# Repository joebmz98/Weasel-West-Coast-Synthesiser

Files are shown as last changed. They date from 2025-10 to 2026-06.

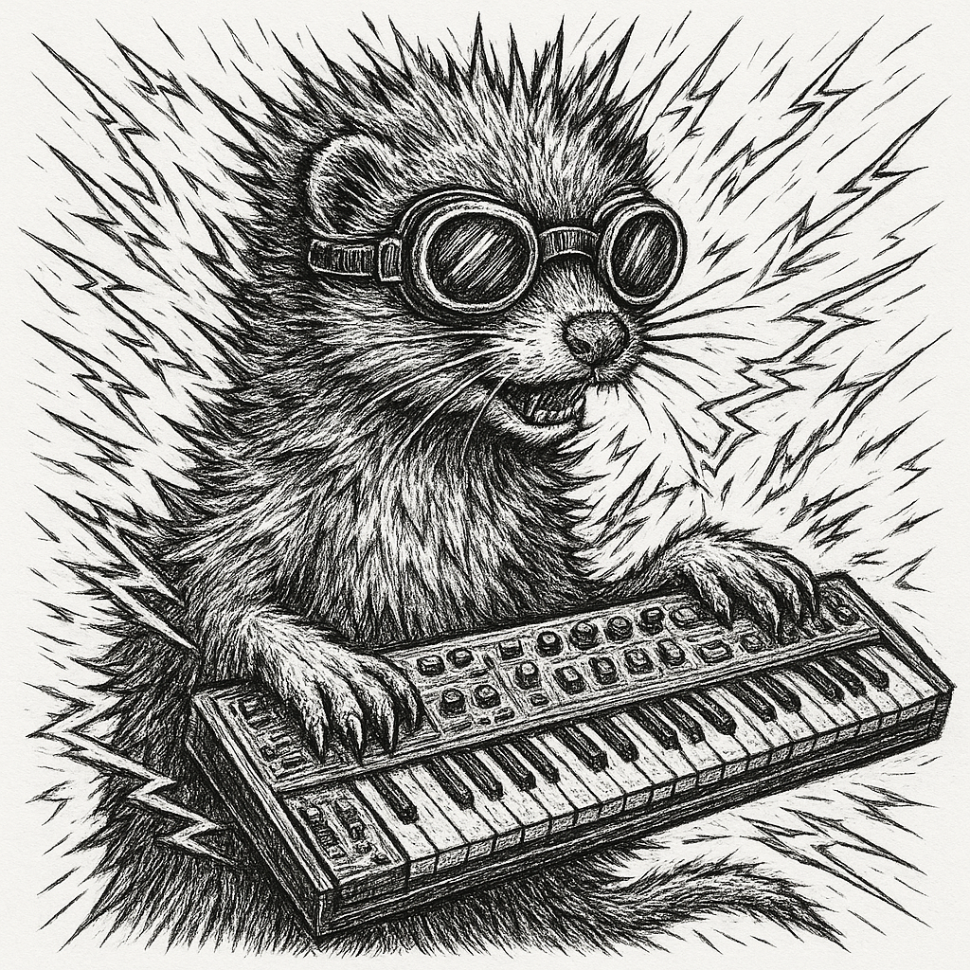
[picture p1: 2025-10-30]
docs/images/weaselDrawing_ai.png

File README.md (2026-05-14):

# WEASEL
### Buchla Music Easel Inspired Digital Synthesizer

**firmware version 0.1** | **hardware version 1.0**

---

Designed by **[.axs instruments](https://github.com/axsinstruments)**

---

## Overview

WEASEL is a digital synthesizer inspired by the iconic Buchla Music Easel, built around the Daisy Seed platform. It features a virtual patch bay that simulates a modular experience, allowing you to route modulation sources to destinations through an intuitive button matrix interface.

---

## Features

- **Complex Oscillator** with sine wave and morphable waveform (saw/triangle/square)
- **Modulation Oscillator** with sine, triangle, saw, and square waveforms
- **FM/AM Modulation** between oscillators
- **Wavefolder** for complex timbre shaping
- **Dual-channel Low Pass Gate (LPG)** with VCA/LP/COMBI modes
- **Buchla-style ASR Envelope Generator**
- **Pulsar Generator** (decaying envelope for rhythmic triggering)
- **Sample & Hold / Random Voltage Generator**
- **5-Step Sequencer** with per-step enable toggles
- **Virtual Patch Bay** (4x7 button matrix) for routing:
  - Sequencer CV → 7 destinations
  - Envelope → 7 destinations
  - Pulsar → 7 destinations
  - Random Voltage → 7 destinations
- **Internal Reverb**
- **MIDI Input** for note control and triggering

---

## Hardware Requirements

| Component | Details |
|---|---|
| **Microcontroller** | Daisy Seed |
| **ADC Resolution** | 16-bit |
| **Potentiometers** | 32 total (via 2x 16-channel multiplexers) |
| **Button Matrix 1** | 4x7 (virtual patch bay) |
| **Button Matrix 2** | 4x5 (mode selection & controls) |
| **Audio Output** | Stereo line out |
| **MIDI Input** | 3.5mm TRS (pin D14 / USART1 Rx) |

### Pin Mapping

**MUX1 (Pots 0-15)** – A0

| MUX Pin | Function |
|---|---|
| S0 | D0 |
| S1 | D1 |
| S2 | D2 |
| S3 | D3 |

**MUX2 (Pots 16-31)** – A1

| MUX Pin | Function |
|---|---|
| S0 | D4 |
| S1 | D5 |
| S2 | D6 |
| S3 | D7 |

---

## Potentiometer Functions

### MUX1 (Channels 0-15)

| CH | Function |
|----|---|
| 0 | Sequencer Step 1 CV |
| 1 | Sequencer Step 2 CV |
| 2 | Sequencer Step 3 CV |
| 3 | Sequencer Step 4 CV |
| 4 | Sequencer Step 5 CV |
| 5 | Attack Time |
| 6 | Sustain Duration |
| 7 | Decay/Release Time |
| 8 | Pulsar Period Modulation Control |
| 9 | Pulsar Period |
| 10 | Modulation Osc Freq Modulation Amount |
| 11 | Modulation Osc Frequency |
| 12 | Modulation Osc Fine Tune (±3 cents) |
| 13 | Modulation Osc Modulation Amount Depth |
| 14 | Modulation Osc Modulation Amount |
| 15 | Complex Osc Frequency Modulation Amount |

### MUX2 (Channels 16-31)

| CH | Function |
|----|---|
| 16 | Complex Osc Frequency |
| 17 | Complex Osc Fine Tune (±3 cents) |
| 18 | Complex Osc Wavefolder Modulation Amount |
| 19 | Complex Osc Wavefolder |
| 20 | Complex Osc Timbre (morph) |
| 21 | LPG1 Modulation Amount |
| 22 | LPG1 Level |
| 23 | LPG2 Modulation Amount |
| 24 | LPG2 Level |
| 25 | Clock Speed |
| 26 | Reverb Mix |
| 27-31 | Not Connected |

---

## Button Matrix Functions

### Matrix 1 (4x7) – Virtual Patch Bay

**Sources (Columns):**
- Col 0: Sequencer CV
- Col 1: Envelope
- Col 2: Pulsar
- Col 3: Random Voltage

**Destinations (Rows):**
- Row 0: Pulsar Period
- Row 1: Modulation Osc Frequency
- Row 2: Modulation Osc Modulation Amount
- Row 3: Complex Osc Pitch
- Row 4: Complex Osc Wavefolder Amount
- Row 5: LPG Channel 1 Level
- Row 6: LPG Channel 2 Level

### Matrix 2 (4x5) – Mode Controls

| Position | Function |
|---|---|
| X0+Y0 | Sequencer Length Cycle (3/4/5 steps) |
| X0+Y1 | Pulsar Mode Toggle (SEQ/MIDI/OSC) |
| X0+Y2 | Complex Osc Polarity Invert |
| X0+Y3 | Mod Osc LPG Mode Toggle (VCA/LP/COMBI) |
| X0+Y4 | Sequencer Step 2 Toggle |
| X1+Y0 | Sequencer Trigger Mode (CLOCK/PULSAR/MIDI) |
| X1+Y1 | Pulsar Clock Mode |
| X1+Y2 | MIDI Toggle (Complex + Mod Osc) |
| X1+Y3 | Random Trigger Mode (SEQ/PULSAR/MIDI) |
| X1+Y4 | Sequencer Step 3 Toggle |
| X2+Y1 | Mod Waveform Cycle |
| X2+Y2 | Complex Waveform Cycle |
| X2+Y4 | Sequencer Step 4 Toggle |
| X3+Y1 | FM/AM Toggle |
| X3+Y2 | LPG Mode Toggle (VCA/LP/COMBI) |
| X3+Y3 | Sequencer Step 1 Toggle |
| X3+Y4 | Sequencer Step 5 Toggle |

---

## Installation & Setup

### 1. Prerequisites

- [Arduino IDE](https://www.arduino.cc/en/software)
- [DaisyDuino](https://github.com/electro-smith/DaisyDuino) – Daisy platform for Arduino
- [MIDI Library](https://github.com/FortySevenEffects/arduino_midi_library)

### 2. Flashing the Firmware

1. Install DaisyDuino following the [official guide](https://github.com/electro-smith/DaisyDuino#installation)
2. Clone this repository
3. Open `weasel.ino` in Arduino IDE
4. Select **Daisy Seed** as the board
5. Upload the firmware

### 3. First Boot

- Connect audio output to the Daisy Seed's audio jack
- Connect a MIDI source to the TRS input (optional)
- Power via USB or external 5V
- The synthesizer will start with default settings

---

## Usage

### Basic Signal Flow

[Complex Osc] → [Wavefolder] → [LPG Ch1] → [Mixer] → [Output Filter] → [Reverb]
[Mod Osc] ──────────────────→ [LPG Ch2] ↗
     ↓
  (FM/AM to Complex Osc)

### Sequencer Operation

- The 5-step sequencer advances based on the selected trigger mode (Clock/Pulsar/MIDI)
- Each step's CV is set by its corresponding potentiometer
- Per-step toggles allow disabling individual steps
- Sequence length can be set to 3, 4, or 5 steps

### Envelope (Buchla ASR Style)

- **Attack**: Sets rise time
- **Sustain**: Sets gate duration
- **Release**: Sets fall time after gate ends

### Pulsar Generator

- Creates decaying envelopes for rhythmic triggering
- Can be synced to sequencer, MIDI note-on, or run freely as an LFO

### Low Pass Gate Modes

- **VCA**: Amplitude only (no filtering)
- **LP**: Low-pass filtering only
- **COMBI**: Both VCA and filtering (classic Buchla LPG behavior)

---

## MIDI Implementation

| Function | Details |
|---|---|
| **Input** | 3.5mm TRS (Type A) |
| **Baud Rate** | 31250 |
| **Note On** | Triggers sequencer, pulsar, and random (depending on mode) |
| **Note Pitch** | Controls Complex and/or Mod Osc frequencies when MIDI mode is enabled |

**MIDI Pin:** Digital pin 30 (D14 / USART1 Rx)

---

## Building from Source

### Dependencies

- `DaisyDuino` – Daisy hardware abstraction
- `MIDI` – MIDI input handling

### Compilation

The firmware is compatible with Arduino IDE. Select **Daisy Seed** from the boards menu and upload.

---

## License

**MIT License** – Copyright (c) 2024 .axs instruments

Permission is hereby granted, free of charge, to any person obtaining a copy of this software and associated documentation files, to deal in the Software without restriction, including without limitation the rights to use, copy, modify, merge, publish, distribute, sublicense, and/or sell copies of the Software.

THE SOFTWARE IS PROVIDED "AS IS", WITHOUT WARRANTY OF ANY KIND, EXPRESS OR IMPLIED.

---

## Support & Contributions

- **Issues:** Open a GitHub ticket
- **Custom Requests:** [axs.instruments@gmail.com](mailto:axs.instruments@gmail.com)
- **Contributions:** PRs welcome!

---

## Acknowledgments

Built with the [Daisy Platform](https://www.electro-smith.com/daisy) by Electro-Smith.

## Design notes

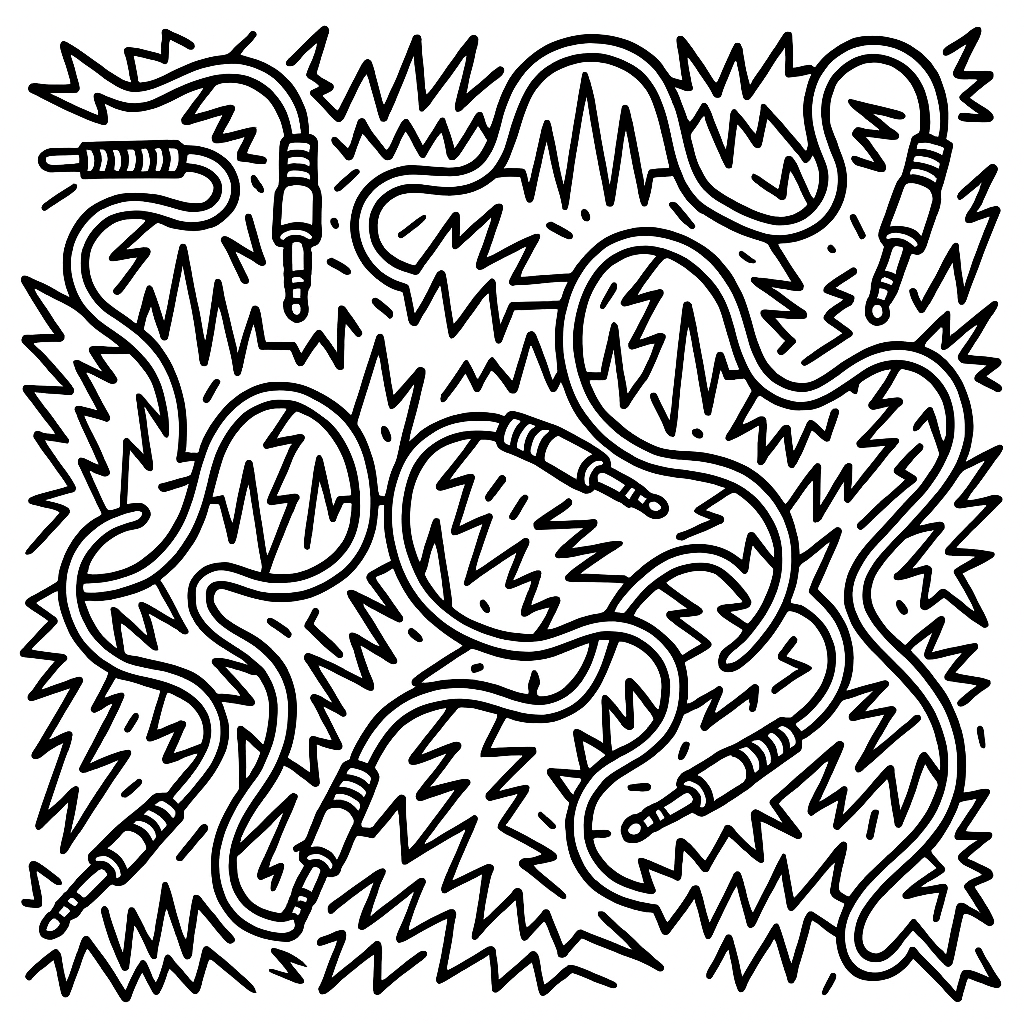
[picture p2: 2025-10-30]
docs/images/modularCables2_ai.png

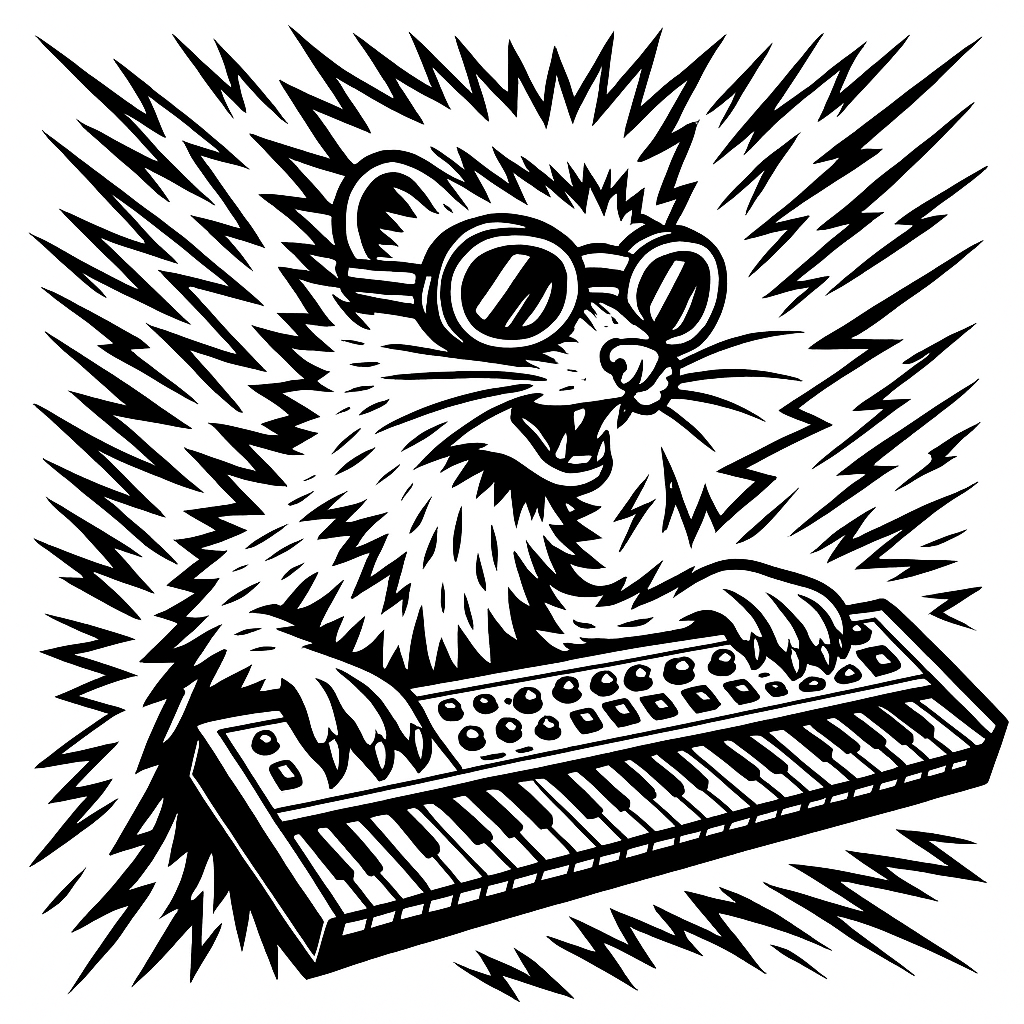
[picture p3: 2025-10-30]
docs/images/weaselDrawing2_ai.png

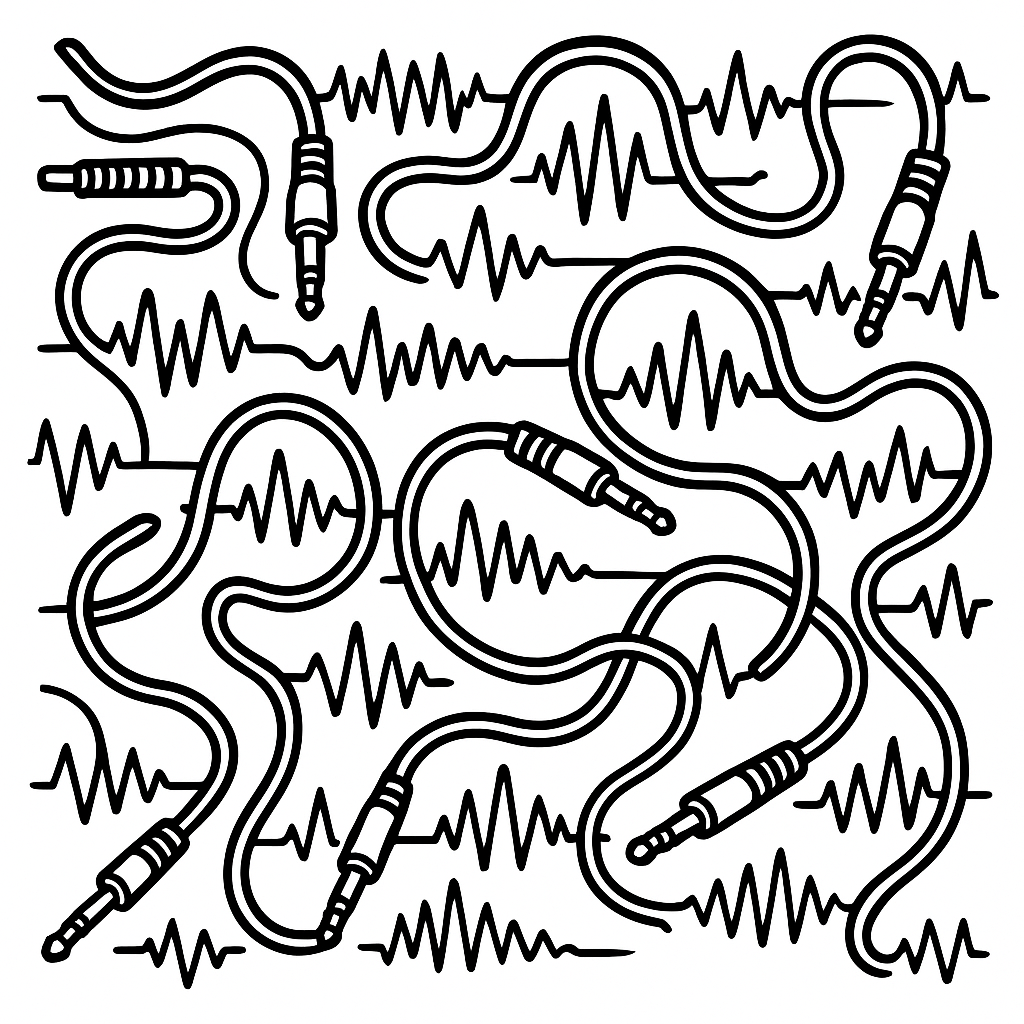
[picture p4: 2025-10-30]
docs/images/modularCables_ai.png

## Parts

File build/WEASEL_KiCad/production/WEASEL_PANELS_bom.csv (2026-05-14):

Designator | Footprint | Quantity | Value | LCSC Part #
_2, |  | 2

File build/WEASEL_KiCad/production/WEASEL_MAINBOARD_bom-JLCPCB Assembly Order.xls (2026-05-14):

JLCPCB BOM Tool - BOM Matching
BOM name：WEASEL_MAINBOARD_bom-JLCPCB Assembly Order.xlsx |  |  | Download Time：2026-05-14 16:15:40 |  |  |  | * Our matching results are updated in real-time, but stock and prices may change. If it's been over 24 hours, please re-match before placing your order.
PCB Assembled Qty：5 |  |  | Est. Total Price：88.7256
Your BOM |  |  |  |  | Matched Parts |  |  |  |  |  |  | Order Information
Top Designator | Bottom Designator | Comment | Footprint | JLCPCB Part # | Matches | Part # | Manufacturer | Footprint | Description | Category | Warning | JLCPCB Part # | Product link | Lib Type | Qty | Source | Total Price ($)
C1,C2,C31,C34,C35,C36,C37,C38,C39,C40,C41 |  | 100nF_0603_16V | 1206 |  | Select by Customer | CL31B104KCFNNNE | Samsung Electro-Mechanics | 1206 | 100V 100nF X7R ±10% 1206 Multilayer Ceramic Capacitors MLCC - SMD/SMT ROHS | Multilayer Ceramic Capacitors MLCC - SMD/SMT |  | C1945 | https://jlcpcb.com/partdetail/2297-CL31B104KCFNNNE/C1945 | Extended | 63 | 63 JLCPCB | 1.1466
C10,C11,C12,C13,C14,C15,C16,C17,C18,C19,C20,C21,C22,C23,C24,C25,C26,C27,C28,C29,C3,C30,C4,C5,C6,C7,C8,C9 |  | C_Generic | 1206 |  | Select by Customer | 1206B103K102NT | FH (Guangdong Fenghua Advanced Tech) | 1206 | 10nF 1kV X7R ±10% 1206 Multilayer Ceramic Capacitors MLCC - SMD/SMT ROHS | Multilayer Ceramic Capacitors MLCC - SMD/SMT |  | C9194 | https://jlcpcb.com/partdetail/9719-1206B103K102NT/C9194 | Extended | 150 | 150 JLCPCB | 1.8
C32 |  | 10uF | 1206 |  | Select by Customer | CL31A106KOHNNNE | Samsung Electro-Mechanics | 1206 | 10uF 16V X5R ±10% 1206 Multilayer Ceramic Capacitors MLCC - SMD/SMT ROHS | Multilayer Ceramic Capacitors MLCC - SMD/SMT |  | C1849 | https://jlcpcb.com/partdetail/2201-CL31A106KOHNNNE/C1849 | Extended | 15 | 15 JLCPCB | 0.5985
D1,D10,D11,D12,D13,D23,D24,D25,D26,D27,D28,D29 |  | 1N4148 | D_SOD-123 |  | Select by Customer | 1N4148W | Jiangsu Changjing Electronics Technology Co., Ltd. | SOD-123 | 1.25V@150mA 100V 150mA 1uA@75V 2A 4ns 500mW Independent SOD-123 Switching Diodes ROHS | Switching Diodes | 1.The comment (1N4148W) of this part does not match the one (1N4148) provided in your BOM. Please confirm; | C2099 | https://jlcpcb.com/partdetail/2456-1N4148W/C2099 | Extended | 72 | 72 JLCPCB | 0.72
D2 |  | 1N5817 | 1206 |  | Select by Customer | 1N5817W | TWGMC | SOD-123 | -55℃~+150℃ 1A 1mA 20V 25A 750mV@3A Independent SOD-123 Schottky Diodes ROHS | Schottky Diodes | 1.The footprint (SOD-123) of this part does not match the one (1206) provided in your BOM. Please confirm; 2.The comment (1N5817W) of this part does not match the one (1N5817) provided in your BOM. Please confirm; | C727113 | https://jlcpcb.com/partdetail/TWGMC-1N5817W/C727113 | Extended | 15 | 15 JLCPCB | 0.3075
D14,D15,D16,D17,D18,D19,D20,D21,D22,D3,D30,D31,D32,D33,D34,D35,D36,D37,D38,D39,D4,D40,D41,D42,D43,D44,D45,D46,D47,D48,D49,D5,D50,D51,D52,D53,D54,D55,D56,D57,D58,D59,D6,D60,D61,D62,D63,D64,D65,D7,D8,D9 |  | LED | 0603 |  | Select by Customer | KT-0603B | Hubei KENTO Elec | 0603 | 100mW 120° 175mcd 3.1V 460nm~475nm 469nm 5mA Blue Discrete Diode Water Clear 0603 LED Indication - Discrete ROHS | LED Indication - Discrete | 1.The comment (KT-0603B) of this part does not match the one (LED) provided in your BOM. Please confirm; | C2288 | https://jlcpcb.com/partdetail/Hubei_KENTOElec-KT0603B/C2288 | Extended | 270 | 270 JLCPCB | 2.754
F1 |  | 1A_15V | 1812 |  | Select by Customer | mSMD050-15V | TECHFUSE | 1812 | 100A 150ms 150mΩ 15V 1A 1Ω 500mA 800mW 1812 Resettable Fuses ROHS | Resettable Fuses |  | C70110 | https://jlcpcb.com/partdetail/TECHFUSE-mSMD05015V/C70110 | Extended | 9 | 9 JLCPCB | 0.369
R1 |  | 220R | R_0603 |  | Select by Customer | 0603WAF2200T5E | UNI-ROYAL(Uniroyal Elec) | 0603 | -55℃~+155℃ 100mW 220Ω 75V Thick Film Resistor ±1% ±100ppm/℃ 0603 Chip Resistor - Surface Mount ROHS | Chip Resistor - Surface Mount | 1.The comment (0603WAF2200T5E) of this part does not match the one (220R) provided in your BOM. Please confirm; | C22962 | https://jlcpcb.com/partdetail/23689-0603WAF2200T5E/C22962 | Basic | 5 | 5 JLCPCB | 0.0075
R2 |  | 470R | R_0603 |  | Select by Customer | 0603WAF4700T5E | UNI-ROYAL(Uniroyal Elec) | 0603 | -55℃~+155℃ 100mW 470Ω 75V Thick Film Resistor ±1% ±100ppm/℃ 0603 Chip Resistor - Surface Mount ROHS | Chip Resistor - Surface Mount | 1.The comment (0603WAF4700T5E) of this part does not match the one (470R) provided in your BOM. Please confirm; | C23179 | https://jlcpcb.com/partdetail/23906-0603WAF4700T5E/C23179 | Basic | 5 | 5 JLCPCB | 0.0085
R3 |  | 1k | R_0603 |  | Select by Customer | 0603WAF1001T5E | UNI-ROYAL(Uniroyal Elec) | 0603 | -55℃~+155℃ 100mW 1kΩ 75V Thick Film Resistor ±1% ±100ppm/℃ 0603 Chip Resistor - Surface Mount ROHS | Chip Resistor - Surface Mount | 1.The comment (0603WAF1001T5E) of this part does not match the one (1k) provided in your BOM. Please confirm; | C21190 | https://jlcpcb.com/partdetail/21904-0603WAF1001T5E/C21190 | Basic | 5 | 5 JLCPCB | 0.008
R10,R11,R12,R13,R14,R15,R16,R17,R18,R19,R20,R21,R22,R23,R24,R25,R26,R27,R4,R5,R6,R7,R8,R9 |  | 10k_0402 | R_0603 |  | Select by Customer | 0603WAF1002T5E | UNI-ROYAL(Uniroyal Elec) | 0603 | -55℃~+155℃ 100mW 10kΩ 75V Thick Film Resistor ±1% ±100ppm/℃ 0603 Chip Resistor - Surface Mount ROHS | Chip Resistor - Surface Mount | 1.The comment (0603WAF1002T5E) of this part does not match the one (10k_0402) provided in your BOM. Please confirm; | C25804 | https://jlcpcb.com/partdetail/26547-0603WAF1002T5E/C25804 | Basic | 120 | 120 JLCPCB | 0.12
SW1 |  | SEQ_TRIGGERSELECT | SW_PUSH_6mm_H13mm |  | Select by Customer | UK-B0202G100-DP25Y | USAKRO | 插件-4P,6x6mm | -20℃~+70℃ 100,000 cycles 10mm 12V 2.5N 50mA 6mm 6mm Black No PC Pin Round Button SPST Through Hole Without Bracket 插件-4P,6x6mm Tactile Switches ROHS | Tactile Switches | 1.Multiple lines in the BOM have been matched to the same part. Please check if the matching is correct. ; | C493222 | https://jlcpcb.com/partdetail/USAKRO-UK_B0202G100DP25Y/C493222 | Extended | 76 | 76 JLCPCB | 4.1724
SW2 |  | SEQ_STAGES | SW_PUSH_6mm_H13mm |  | Select by Customer | UK-B0202G100-DP25Y | USAKRO | 插件-4P,6x6mm | -20℃~+70℃ 100,000 cycles 10mm 12V 2.5N 50mA 6mm 6mm Black No PC Pin Round Button SPST Through Hole Without Bracket 插件-4P,6x6mm Tactile Switches ROHS | Tactile Switches | 1.Multiple lines in the BOM have been matched to the same part. Please check if the matching is correct. ; | C493222 | https://jlcpcb.com/partdetail/USAKRO-UK_B0202G100DP25Y/C493222 | Extended | 76 | 76 JLCPCB | 4.1724
SW3 |  | EG_TRIGGERSELECT | SW_PUSH_6mm_H13mm |  | Select by Customer | UK-B0202G100-DP25Y | USAKRO | 插件-4P,6x6mm | -20℃~+70℃ 100,000 cycles 10mm 12V 2.5N 50mA 6mm 6mm Black No PC Pin Round Button SPST Through Hole Without Bracket 插件-4P,6x6mm Tactile Switches ROHS | Tactile Switches | 1.Multiple lines in the BOM have been matched to the same part. Please check if the matching is correct. ; | C493222 | https://jlcpcb.com/partdetail/USAKRO-UK_B0202G100DP25Y/C493222 | Extended | 76 | 76 JLCPCB | 4.1724
SW4 |  | EG_MODESELECT | SW_PUSH_6mm_H13mm |  | Select by Customer | UK-B0202G100-DP25Y | USAKRO | 插件-4P,6x6mm | -20℃~+70℃ 100,000 cycles 10mm 12V 2.5N 50mA 6mm 6mm Black No PC Pin Round Button SPST Through Hole Without Bracket 插件-4P,6x6mm Tactile Switches ROHS | Tactile Switches | 1.Multiple lines in the BOM have been matched to the same part. Please check if the matching is correct. ; | C493222 | https://jlcpcb.com/partdetail/USAKRO-UK_B0202G100DP25Y/C493222 | Extended | 76 | 76 JLCPCB | 4.1724
SW5 |  | PLSR_TRIGGERSELECT | SW_PUSH_6mm_H13mm |  | Select by Customer | UK-B0202G100-DP25Y | USAKRO | 插件-4P,6x6mm | -20℃~+70℃ 100,000 cycles 10mm 12V 2.5N 50mA 6mm 6mm Black No PC Pin Round Button SPST Through Hole Without Bracket 插件-4P,6x6mm Tactile Switches ROHS | Tactile Switches | 1.Multiple lines in the BOM have been matched to the same part. Please check if the matching is correct. ; | C493222 | https://jlcpcb.com/partdetail/USAKRO-UK_B0202G100DP25Y/C493222 | Extended | 76 | 76 JLCPCB | 4.1724
SW6 |  | PLSR_MODE | SW_PUSH_6mm_H13mm |  | Select by Customer | UK-B0202G100-DP25Y | USAKRO | 插件-4P,6x6mm | -20℃~+70℃ 100,000 cycles 10mm 12V 2.5N 50mA 6mm 6mm Black No PC Pin Round Button SPST Through Hole Without Bracket 插件-4P,6x6mm Tactile Switches ROHS | Tactile Switches | 1.Multiple lines in the BOM have been matched to the same part. Please check if the matching is correct. ; | C493222 | https://jlcpcb.com/partdetail/USAKRO-UK_B0202G100DP25Y/C493222 | Extended | 76 | 76 JLCPCB | 4.1724
SW7 |  | MODOSC_MODULATIONMODE | SW_PUSH_6mm_H13mm |  | Select by Customer | UK-B0202G100-DP25Y | USAKRO | 插件-4P,6x6mm | -20℃~+70℃ 100,000 cycles 10mm 12V 2.5N 50mA 6mm 6mm Black No PC Pin Round Button SPST Through Hole Without Bracket 插件-4P,6x6mm Tactile Switches ROHS | Tactile Switches | 1.Multiple lines in the BOM have been matched to the same part. Please check if the matching is correct. ; | C493222 | https://jlcpcb.com/partdetail/USAKRO-UK_B0202G100DP25Y/C493222 | Extended | 76 | 76 JLCPCB | 4.1724
SW8 |  | MODOSC_WAVEFORMTOGGLE | SW_PUSH_6mm_H13mm |  | Select by Customer | UK-B0202G100-DP25Y | USAKRO | 插件-4P,6x6mm | -20℃~+70℃ 100,000 cycles 10mm 12V 2.5N 50mA 6mm 6mm Black No PC Pin Round Button SPST Through Hole Without Bracket 插件-4P,6x6mm Tactile Switches ROHS | Tactile Switches | 1.Multiple lines in the BOM have been matched to the same part. Please check if the matching is correct. ; | C493222 | https://jlcpcb.com/partdetail/USAKRO-UK_B0202G100DP25Y/C493222 | Extended | 76 | 76 JLCPCB | 4.1724
SW9 |  | OSCILLATOR_MIDITOGGLE | SW_PUSH_6mm_H13mm |  | Select by Customer | UK-B0202G100-DP25Y | USAKRO | 插件-4P,6x6mm | -20℃~+70℃ 100,000 cycles 10mm 12V 2.5N 50mA 6mm 6mm Black No PC Pin Round Button SPST Through Hole Without Bracket 插件-4P,6x6mm Tactile Switches ROHS | Tactile Switches | 1.Multiple lines in the BOM have been matched to the same part. Please check if the matching is correct. ; | C493222 | https://jlcpcb.com/partdetail/USAKRO-UK_B0202G100DP25Y/C493222 | Extended | 76 | 76 JLCPCB | 4.1724
SW10 |  | COMPLEXOSC_POLARITY | SW_PUSH_6mm_H13mm |  | Select by Customer | UK-B0202G100-DP25Y | USAKRO | 插件-4P,6x6mm | -20℃~+70℃ 100,000 cycles 10mm 12V 2.5N 50mA 6mm 6mm Black No PC Pin Round Button SPST Through Hole Without Bracket 插件-4P,6x6mm Tactile Switches ROHS | Tactile Switches | 1.Multiple lines in the BOM have been matched to the same part. Please check if the matching is correct. ; | C493222 | https://jlcpcb.com/partdetail/USAKRO-UK_B0202G100DP25Y/C493222 | Extended | 76 | 76 JLCPCB | 4.1724
SW11 |  | COMPLEXOSC_WAVETOGGLE | SW_PUSH_6mm_H13mm |  | Select by Customer | UK-B0202G100-DP25Y | USAKRO | 插件-4P,6x6mm | -20℃~+70℃ 100,000 cycles 10mm 12V 2.5N 50mA 6mm 6mm Black No PC Pin Round Button SPST Through Hole Without Bracket 插件-4P,6x6mm Tactile Switches ROHS | Tactile Switches | 1.Multiple lines in the BOM have been matched to the same part. Please check if the matching is correct. ; | C493222 | https://jlcpcb.com/partdetail/USAKRO-UK_B0202G100DP25Y/C493222 | Extended | 76 | 76 JLCPCB | 4.1724
SW12 |  | LPG_GATE1MODE | SW_PUSH_6mm_H13mm |  | Select by Customer | UK-B0202G100-DP25Y | USAKRO | 插件-4P,6x6mm | -20℃~+70℃ 100,000 cycles 10mm 12V 2.5N 50mA 6mm 6mm Black No PC Pin Round Button SPST Through Hole Without Bracket 插件-4P,6x6mm Tactile Switches ROHS | Tactile Switches | 1.Multiple lines in the BOM have been matched to the same part. Please check if the matching is correct. ; | C493222 | https://jlcpcb.com/partdetail/USAKRO-UK_B0202G100DP25Y/C493222 | Extended | 76 | 76 JLCPCB | 4.1724
SW13 |  | LPG_GATE2MODE | SW_PUSH_6mm_H13mm |  | Select by Customer | UK-B0202G100-DP25Y | USAKRO | 插件-4P,6x6mm | -20℃~+70℃ 100,000 cycles 10mm 12V 2.5N 50mA 6mm 6mm Black No PC Pin Round Button SPST Through Hole Without Bracket 插件-4P,6x6mm Tactile Switches ROHS | Tactile Switches | 1.Multiple lines in the BOM have been matched to the same part. Please check if the matching is correct. ; | C493222 | https://jlcpcb.com/partdetail/USAKRO-UK_B0202G100DP25Y/C493222 | Extended | 76 | 76 JLCPCB | 4.1724
SW14 |  | RNDMVOLTAGE_TRIGGERSELECT | SW_PUSH_6mm_H13mm |  | Select by Customer | UK-B0202G100-DP25Y | USAKRO | 插件-4P,6x6mm | -20℃~+70℃ 100,000 cycles 10mm 12V 2.5N 50mA 6mm 6mm Black No PC Pin Round Button SPST Through Hole Without Bracket 插件-4P,6x6mm Tactile Switches ROHS | Tactile Switches | 1.Multiple lines in the BOM have been matched to the same part. Please check if the matching is correct. ; | C493222 | https://jlcpcb.com/partdetail/USAKRO-UK_B0202G100DP25Y/C493222 | Extended | 76 | 76 JLCPCB | 4.1724
SW15 |  | CLOCK_SYNCTOGGLE | SW_PUSH_6mm_H13mm |  | Select by Customer | UK-B0202G100-DP25Y | USAKRO | 插件-4P,6x6mm | -20℃~+70℃ 100,000 cycles 10mm 12V 2.5N 50mA 6mm 6mm Black No PC Pin Round Button SPST Through Hole Without Bracket 插件-4P,6x6mm Tactile Switches ROHS | Tactile Switches | 1.Multiple lines in the BOM have been matched to the same part. Please check if the matching is correct. ; | C493222 | https://jlcpcb.com/partdetail/USAKRO-UK_B0202G100DP25Y/C493222 | Extended | 76 | 76 JLCPCB | 4.1724
U1,U10,U11,U2 |  | AW9523B | QFN-24-1EP_4x4mm_P0.5mm_EP2.7x2.7mm |  | Select by Customer | AW9523BTQR | AWINIC(Shanghai Awinic Tech) | TQFN-24-EP(4x4) | -40℃~+85℃ 100nA 16 2.4V~5.5V 20mA 4 400kHz 60mV I2C Interrupt Output Push-Pull、Open-drain Reset function、Cascading and address extension、Input anti-jitter、Built-in LED driver、IO level configurable TQFN-24-EP(4x4) I/O Expanders ROHS | I/O Expanders | 1.The comment (AW9523BTQR) of this part does not match the one (AW9523B) provided in your BOM. Please confirm; | C148077 | https://jlcpcb.com/partdetail/159410-AW9523BTQR/C148077 | Extended | 20 | 20 JLCPCB | 6.724
U4,U5 |  | CD74HC4067M | SOIC-24W_7.5x15.4mm_P1.27mm |  | Select by Customer | CD74HC4067M96 | Texas Instruments | SOIC-24-300mil | -55℃~+125℃ 15ns 2V~6V 70Ω 83ns 83ns 89MHz SOIC-24-300mil Analog Switches, Multiplexers ROHS | Analog Switches, Multiplexers | 1.The comment (CD74HC4067M96) of this part does not match the one (CD74HC4067M) provided in your BOM. Please confirm; | C496123 | https://jlcpcb.com/partdetail/TexasInstruments-CD74HC4067M96/C496123 | Extended | 10 | 10 JLCPCB | 7.522
U6,U7,U8,U9 |  | 74HC165 | SOIC-16_3.9x9.9mm_P1.27mm |  | Select by System | 74HC165D,653 | Nexperia | SOIC-16 | -40℃~+125℃ 1 28ns@6V,50pF 2V~6V 35MHz 500mW 74HC 8 Parallel or Serial to Serial SOIC-16 Shift Registers ROHS | Shift Registers |  | C5613 | https://jlcpcb.com/partdetail/Nexperia-74HC165D653/C5613 | Extended | 20 | 20 JLCPCB | 4.054
U3 |  | 6N138 | SOP-8_6.62x9.15mm_P2.54mm |  | Select by System | 6N138 | Everlight Elec | DIP-8 | -40℃~+85℃ 1 1.3V 5kV 60mA DIP-8 Transistor, Photovoltaic Output Optoisolators ROHS | Transistor, Photovoltaic Output Optoisolators |  | C5274131 | https://jlcpcb.com/partdetail/EverlightElec-6N138/C5274131 | Extended | 5 | 0 JLCPCB | 0
C33 |  | 100uF_25V | CP_Radial_D6.3mm_P2.50mm |  | No matches | No Part Selected
J22 |  | Jack-DC | BarrelJack_GCT_DCJ200-10-A_Horizontal |  | No matches | No Part Selected

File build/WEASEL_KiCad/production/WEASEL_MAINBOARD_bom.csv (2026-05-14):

Designator | Footprint | Quantity | Value | LCSC Part #
A1 | Electrosmith_Daisy_Seed | 1 | Electrosmith_Daisy_Seed_Rev4
C1, C2, C31, C34, C35, C36, C37, C38, C39, C40, C41 | 1206 | 11 | 100nF_0603_16V
C10, C11, C12, C13, C14, C15, C16, C17, C18, C19, C20, C21, C22, C23, C24, C25, C26, C27, C28, C29, C3, C30, C4, C5, C6, C7, C8, C9 | 1206 | 28 | C_Generic
C32 | 1206 | 1 | 10uF
C33 | CP_Radial_D6.3mm_P2.50mm | 1 | 100uF_25V
D1, D10, D11, D12, D13, D23, D24, D25, D26, D27, D28, D29 | D_SOD-123 | 12 | 1N4148
D14, D15, D16, D17, D18, D19, D20, D21, D22, D3, D30, D31, D32, D33, D34, D35, D36, D37, D38, D39, D4, D40, D41, D42, D43, D44, D45, D46, D47, D48, D49, D5, D50, D51, D52, D53, D54, D55, D56, D57, D58, D59, D6, D60, D61, D62, D63, D64, D65, D7, D8, D9 | 0603 | 52 | LED
D2 | D_SOD-123 | 1 | 1N5817
F1 | 1812 | 1 | 1A_15V
J1 | Jack_3.5mm_CUI_SJ1-3525N_Horizontal | 1 | MIDI IN
J10 | Jack_3.5mm_QingPu_WQP-PJ398SM_Vertical_CircularHoles | 1 | PLSR_OUTPUT2
J11 | Jack_3.5mm_QingPu_WQP-PJ398SM_Vertical_CircularHoles | 1 | PLSR_OUTPUT3
J12 | Jack_3.5mm_QingPu_WQP-PJ398SM_Vertical_CircularHoles | 1 | RNDM_OUTPUT1
J13 | Jack_3.5mm_QingPu_WQP-PJ398SM_Vertical_CircularHoles | 1 | RNDM_OUTPUT2
J14 | Jack_3.5mm_QingPu_WQP-PJ398SM_Vertical_CircularHoles | 1 | RNDM_OUTPUT3
J15 | Jack_3.5mm_QingPu_WQP-PJ398SM_Vertical_CircularHoles | 1 | PLSR_PERIODCTRL
J16 | Jack_3.5mm_QingPu_WQP-PJ398SM_Vertical_CircularHoles | 1 | MODOSC_FREQCTRL
J17 | Jack_3.5mm_QingPu_WQP-PJ398SM_Vertical_CircularHoles | 1 | MODOSC_MODCTRL
J18 | Jack_3.5mm_QingPu_WQP-PJ398SM_Vertical_CircularHoles | 1 | COMPOSC_PITCHCTRL
J19 | Jack_3.5mm_QingPu_WQP-PJ398SM_Vertical_CircularHoles | 1 | COMPOSC_WAVEFOLDERCTRL
J2 | Jack_3.5mm_CUI_SJ1-3525N_Horizontal | 1 | STEREO_OUTPUT
J20 | Jack_3.5mm_QingPu_WQP-PJ398SM_Vertical_CircularHoles | 1 | LPG_LEVEL1CTRL
J21 | Jack_3.5mm_QingPu_WQP-PJ398SM_Vertical_CircularHoles | 1 | LPG_LEVEL2CTRL
J22 | BarrelJack_GCT_DCJ200-10-A_Horizontal | 1 | Jack-DC
J3 | Jack_3.5mm_QingPu_WQP-PJ398SM_Vertical_CircularHoles | 1 | SEQ_OUTPUT1
J4 | Jack_3.5mm_QingPu_WQP-PJ398SM_Vertical_CircularHoles | 1 | SEQ_OUTPUT2
J5 | Jack_3.5mm_QingPu_WQP-PJ398SM_Vertical_CircularHoles | 1 | SEQ_OUTPUT3
J6 | Jack_3.5mm_QingPu_WQP-PJ398SM_Vertical_CircularHoles | 1 | EG_OUTPUT1
J7 | Jack_3.5mm_QingPu_WQP-PJ398SM_Vertical_CircularHoles | 1 | EG_OUTPUT2
J8 | Jack_3.5mm_QingPu_WQP-PJ398SM_Vertical_CircularHoles | 1 | EG_OUTPUT3
J9 | Jack_3.5mm_QingPu_WQP-PJ398SM_Vertical_CircularHoles | 1 | PLSR_OUTPUT1
R1 | R_0603 | 1 | 220R
R10, R11, R12, R13, R14, R15, R16, R17, R18, R19, R20, R21, R22, R23, R24, R25, R26, R27, R4, R5, R6, R7, R8, R9 | R_0603 | 24 | 10k_0402
R2 | R_0603 | 1 | 470R
R3 | R_0603 | 1 | 1k
RV1 | Potentiometer_Bourns_PTA2043_Single_Slide | 1 | SQ_Step1
RV10 | Potentiometer_Bourns_PTA2043_Single_Slide | 1 | PLSR_PERIOD
RV11 | Potentiometer_Bourns_PTA2043_Single_Slide | 1 | MODOSC_FREQCTRL
RV12 | Potentiometer_Bourns_PTA2043_Single_Slide | 1 | MODOSC_FREQ
RV13 | Potentiometer_Bourns_PTA2043_Single_Slide | 1 | MODOSC_MODULATIONCTRL
RV14 | Potentiometer_Bourns_PTA2043_Single_Slide | 1 | MODOSC_MODULATION
RV15 | Potentiometer_RV09 | 1 | MODOSC_FINE
RV16 | Potentiometer_Bourns_PTA2043_Single_Slide | 1 | COMPLEXOSC_FREQCTRL
RV17 | Potentiometer_Bourns_PTA2043_Single_Slide | 1 | COMPLEXOSC_FREQ
RV18 | Potentiometer_RV09 | 1 | COMPLEXOSC_FINE
RV19 | Potentiometer_Bourns_PTA2043_Single_Slide | 1 | COMPLEXOSC_WAVEFOLDERCTRL
RV2 | Potentiometer_Bourns_PTA2043_Single_Slide | 1 | SQ_Step2
RV20 | Potentiometer_Bourns_PTA2043_Single_Slide | 1 | COMPLEXOSC_WAVEFOLDER
RV21 | Potentiometer_RV09 | 1 | COMPLEXOSC_TIMBRE
RV22 | Potentiometer_Bourns_PTA2043_Single_Slide | 1 | LPG_LEVEL1CTRL
RV23 | Potentiometer_Bourns_PTA2043_Single_Slide | 1 | LPG_LEVEL1
RV24 | Potentiometer_Bourns_PTA2043_Single_Slide | 1 | LPG_LEVEL2CTRL
RV25 | Potentiometer_Bourns_PTA2043_Single_Slide | 1 | LPG_LEVEL2
RV26 | Potentiometer_RV09 | 1 | CLOCK
RV27 | Potentiometer_RV09 | 1 | REVERB_MIX
RV28 | Potentiometer_RV09 | 1 | MASTER
RV3 | Potentiometer_Bourns_PTA2043_Single_Slide | 1 | SQ_Step3
RV4 | Potentiometer_Bourns_PTA2043_Single_Slide | 1 | SQ_Step4
RV5 | Potentiometer_Bourns_PTA2043_Single_Slide | 1 | SQ_Step5
RV6 | Potentiometer_Bourns_PTA2043_Single_Slide | 1 | EG_ATTACK
RV7 | Potentiometer_Bourns_PTA2043_Single_Slide | 1 | EG_SUSTAIN
RV8 | Potentiometer_Bourns_PTA2043_Single_Slide | 1 | EG_DECAY
RV9 | Potentiometer_Bourns_PTA2043_Single_Slide | 1 | PLSR_PERIODCTRL
SW1 | SW_PUSH_6mm_H13mm | 1 | SEQ_TRIGGERSELECT
SW10 | SW_PUSH_6mm_H13mm | 1 | COMPLEXOSC_POLARITY
SW11 | SW_PUSH_6mm_H13mm | 1 | COMPLEXOSC_WAVETOGGLE
SW12 | SW_PUSH_6mm_H13mm | 1 | LPG_GATE1MODE
SW13 | SW_PUSH_6mm_H13mm | 1 | LPG_GATE2MODE
SW14 | SW_PUSH_6mm_H13mm | 1 | RNDMVOLTAGE_TRIGGERSELECT
SW15 | SW_PUSH_6mm_H13mm | 1 | CLOCK_SYNCTOGGLE
SW16 | ToggleSwitch_MTS-102_SPDT | 1 | SQ_TOGGLESTEP1
SW17 | ToggleSwitch_MTS-102_SPDT | 1 | SQ_TOGGLESTEP2
SW18 | ToggleSwitch_MTS-102_SPDT | 1 | SQ_TOGGLESTEP3
SW19 | ToggleSwitch_MTS-102_SPDT | 1 | SQ_TOGGLESTEP4
SW2 | SW_PUSH_6mm_H13mm | 1 | SEQ_STAGES
SW20 | ToggleSwitch_MTS-102_SPDT | 1 | SQ_TOGGLESTEP5
SW3 | SW_PUSH_6mm_H13mm | 1 | EG_TRIGGERSELECT
SW4 | SW_PUSH_6mm_H13mm | 1 | EG_MODESELECT
SW5 | SW_PUSH_6mm_H13mm | 1 | PLSR_TRIGGERSELECT
SW6 | SW_PUSH_6mm_H13mm | 1 | PLSR_MODE
SW7 | SW_PUSH_6mm_H13mm | 1 | MODOSC_MODULATIONMODE
SW8 | SW_PUSH_6mm_H13mm | 1 | MODOSC_WAVEFORMTOGGLE
SW9 | SW_PUSH_6mm_H13mm | 1 | OSCILLATOR_MIDITOGGLE
U1, U10, U11, U2 | QFN-24-1EP_4x4mm_P0.5mm_EP2.7x2.7mm | 4 | AW9523B
U3 | DIP-8_W7.62mm_LongPads | 1 | 6N138
U4, U5 | SOIC-24W_7.5x15.4mm_P1.27mm | 2 | CD74HC4067M
U6, U7, U8, U9 | SOIC-16_3.9x9.9mm_P1.27mm | 4 | 74HC165

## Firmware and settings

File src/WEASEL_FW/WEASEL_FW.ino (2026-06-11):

// ********************** //
// ==== WEASEL ========== //
// Buchla Music Easel     //
// Inspired Digital Synth //
// firmware version 0.1   //
// Hardware Version: 1.0  //
// ********************** //
// designed by            //
// .axs instruments       //
// ********************** //
// Description: Buchla Music Easel nspired digital synth
//              Virtual patch bay simulating modular
//              experience.
// ********************** //

// ********************** //
// LICENSE & COPYRIGHT
//
// This project is released under the MIT License.
// Copyright (c) 2024 .axs instruments
//
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

#include "DaisyDuino.h"

// EXTRA INCLUSIONS
#include <MIDI.h>          // MIDI
#include <CpuLoadMeter.h>  // CPU LOAD METER
#include "wavefolder.h"    // EXTRACTED FROM DAISYSP
#include <math.h>

using namespace daisysp;

// DEBUG
#pragma GCC optimize("O2")

// -- MUX PINS - FIRST MUX
#define MUX1_S0 D0
#define MUX1_S1 D1
#define MUX1_S2 D2
#define MUX1_S3 D3
#define MUX1_SIG A0  // MUX signal pin

// -- MUX PINS - SECOND MUX
#define MUX2_S0 D4
#define MUX2_S1 D5
#define MUX2_S2 D6
#define MUX2_S3 D7
#define MUX2_SIG A1  // Second MUX signal pin

// -- 4x7 BUTTON MATRIX PINS // VIRTUAL PATCH BAY
#define MATRIX_COL0 19  // Column 0 (B0) // SEQUENCER CV OUT
#define MATRIX_COL1 20  // Column 1 (B1) // EG CV OUT
#define MATRIX_COL2 21  // Column 2 (B2) // PULSAR CV OUT
#define MATRIX_COL3 22  // Column 3 (B3) // RANDOM VOLTAGE CV OUT
#define MATRIX_ROW0 23  // Row 0 (A0) // PULSAR PERIOD MODULATION
#define MATRIX_ROW1 24  // Row 1 (A1) // MOD OSC FREQ
#define MATRIX_ROW2 25  // Row 2 (A2) // MOD OSC MOD AMOUNT
#define MATRIX_ROW3 26  // Row 3 (A3) // COMPLEX OSC PITCH
#define MATRIX_ROW4 27  // Row 4 (A4) // COMPLEX OSC WAVEFOLDER AMOUNT
#define MATRIX_ROW5 28  // Row 5 (A5) // LPG CH1 LEVEL MODULATION
#define MATRIX_ROW6 29  // Row 6 (A6) // LPG CH2 LEVEL MODULATION

// -- SECOND BUTTON MATRIX PINS
#define MATRIX2_COL0 12  // X0
#define MATRIX2_COL1 13  // X1
#define MATRIX2_COL2 17  // X2
#define MATRIX2_COL3 18  // X3
#define MATRIX2_ROW0 8   // Y0
#define MATRIX2_ROW1 9   // Y1
#define MATRIX2_ROW2 10  // Y2
#define MATRIX2_ROW3 11  // Y3
#define MATRIX2_ROW4 30  // Y4

// -- BUTTON MATRIX 1 VARIABLES --
bool matrixStates[4][7] = { { false } };
bool lastMatrixStates[4][7] = { { false } };
unsigned long lastMatrixRead = 0;
const unsigned long MATRIX_READ_INTERVAL = 20;

const char* matrix1Functions[4][7] = {
  { "Seq CV -> Pulsar Decay", "Seq CV -> ModOsc Pitch", "Seq CV -> Mod Amount", "Seq CV -> CompOsc Pitch", "Seq CV -> WF Mod", "Seq CV -> LPG1", "Seq CV -> LPG2" },
  { "Env -> Pulsar Decay", "Env -> ModOsc Pitch", "Env -> Mod Amount", "Env -> CompOsc Pitch", "Env -> WF Mod", "Env -> LPG1", "Env -> LPG2" },
  { "Pulsar -> Pulsar Decay", "Pulsar -> ModOsc Pitch", "Pulsar -> Mod Amount", "Pulsar -> CompOsc Pitch", "Pulsar -> WF Mod", "Pulsar -> LPG1", "Pulsar -> LPG2" },
  { "S&H -> Pulsar Decay", "S&H -> ModOsc Pitch", "S&H -> Mod Amount", "S&H -> CompOsc Pitch", "S&H -> WF Mod", "S&H -> LPG1", "S&H -> LPG2" }
};

// -- BUTTON MATRIX 2 --
bool matrix2CurrentStates[4][5] = { { false } };
bool matrix2PreviousStates[4][5] = { { false } };
bool matrix2DebouncedStates[4][5] = { { false } };
unsigned long lastMatrix2Read = 0;

// -- POT VARIABLES --
const int NUM_POTS_PER_MUX = 16;
const int TOTAL_POTS = 32;  // 2 muxes * 16 channels each
int potValues[TOTAL_POTS] = { 0 };
int lastPotValues[TOTAL_POTS] = { 0 };
unsigned long lastPotRead = 0;
const unsigned long POT_READ_INTERVAL = 5;  // Read pots every Xms
String potNames[TOTAL_POTS];                // Array to store pot names
const int POT_THRESHOLD = 2;                //


// -- DAISY DUINO OBJECTS --
DaisyHardware hw;  // DAISY SEED
// -- OSCILLATORS
Oscillator complexOsc;       // COMPLEX OSCILLATOR
Oscillator complexOscMorph;  // COMPLEX MORPH OSCILLATOR
Oscillator modulationOsc;    // COMPLEX OSCILLATOR
// -- ENVELOPE GENERATOR
Adsr env;  // ENV GENERATOR
// -- PULSAR GENERATOR
Adsr pulsar;  // ENV GENERATOR FOR PULSAR
// -- LOW-PASS - LPG
Svf lpGateFilter1;  // FILTER FOR LPG CHAN1
Svf lpGateFilter2;  // FILTER FOR LPG CHAN2
// -- OUTPUT ANALOGUE FILTER
MoogLadder outputFilter;
// -- REVERB
ReverbSc reverb;  // REVERB
// -- WAVEFOLDER
daisysp::Wavefolder waveFolder;


// -- OBJECT VARIABLES --
float sampleRate;
// -- OSCILLATORS
// -- COMPLEX
float complexOscFreq;                 // CONTROLS FREQUENCY
float complexOscFine;                 // CONTROLS FINE TUNE
float complexOscFreqCoeff;            // COEFF FOR FREQUENCY MODULATION USING MATRIX
float complexOscWF;                   // CONTROLS WF AMOUNT
float complexOscWFCoeff;              // COEFF FOR WF MODULATION USING MATRIX
float complexOscWFModDepth = 0.0f;    // WAVEFOLDER MOD DEPTH
float complexOscFreqModDepth = 0.0f;  // FREQ MOD DEPTH
bool complexOscInverted = false;      // TOGGLE POLARITY
bool complexOscMidiEnabled = false;   // TOGGLE MIDI
float complexOscMorphMix;             // COMPLEX OSC TIMBRE AMOUNT
int morphWaveformIndex = 0;           // 0 = SAW, 1 = SQUARE, 2 = TRIANGLE
float complexOscSigLevel = 0.0f;      // LPG CONTROL

// -- MODULATION
float modulationOscFreq = 0.0f;           // CONTROLS FREQUENCY
float modulationFine = 0.0f;              // CONTROLS FINE TUNE
float modulationFreqCoeff = 0.0f;         // COEFF FOR FREQUENCY MODULATION USING MATRIX
float modulationOscMod = 0.0f;            // CONTROLS MOD AMOUNT APPLIED TO COMPLEXOSC
float modulationOscModCoeff;              // COEFF FOR MOD AMOUNT MODULATION USING MATRIX
float modulationFreqModDepth = 0.0f;      // FREQ MOD DEPTH
float modulationOscModCoeffDepth = 0.0f;  // MODULATION MOD DEPTH
bool useAmplitudeMod = false;             // False = FM, True = AM
bool modulationMidiEnabled = false;       // TOGGLE MIDI
int modWaveformIndex = 0;                 // 0: SIN, 1: TRI, 2: SQUARE, 3: SAW
float modOscSigLevel = 0.0f;              // LPG CONTROL

// -- LPG --
float vcaComplexOsc;              // AMPLITUDE COEFF FOR COMPLEXOSC
float vcaModulationOsc;           // AMPLITUDE COEFF FOR MODULATIONOSC
float foldedLpgModAmount = 0.0f;  // Multiplier for Folded LPG mod
float modOscLpgModAmount = 0.0f;  // Multiplier for Mod Osc LPG mod
enum LpgMode { LPG_MODE_VCA,
               LPG_MODE_LP,
               LPG_MODE_COMBI };
LpgMode foldedLpgMode = LPG_MODE_COMBI;  // Default to COMBI mode
LpgMode modOscLpgMode = LPG_MODE_COMBI;  // Default to COMBI mode
float lastCtrl0 = -1.0f;
float lastCtrl1 = -1.0f;
int lastMode0 = -1;
int lastMode1 = -1;
#define LPG_TABLE_SIZE 64
float lpgFreqTable[LPG_TABLE_SIZE];


// -- ENVELOPE [BUCHLA ASD/ASR] --
enum EnvelopeMode { ENV_MODE_TRANSIENT,            // One-shot, cannot sustain
                    ENV_MODE_SUSTAIN,              // Can sustain with gate
                    ENV_MODE_OSCILLATE };          // Looping envelope
EnvelopeMode currentEnvMode = ENV_MODE_TRANSIENT;  // Default to Transient
float attackTime = 0.0f;
float releaseTime = 0.0f;
float sustainDuration = 0.0f;
uint32_t gateRemainingSamples = 0;
uint32_t transientGateSamples = 0;
uint32_t sustainGateSamples = 0;
bool envRetriggerFlag = false;  // For oscillating mode

// -- ENVELOPE TRIGGER SELECT --
enum EnvTriggerMode { ENV_TRIGGER_SEQ,                   // Sequencer steps (default)
                      ENV_TRIGGER_PULSAR,                // Pulsar trigger
                      ENV_TRIGGER_MIDI };                // MIDI note on
EnvTriggerMode currentEnvTriggerMode = ENV_TRIGGER_SEQ;  // Default to Sequencer
bool envTrigger = false;                                 // Separate flag for  triggering
bool envMidiTrigger = false;                             // Separate flag for MIDI triggering
static uint32_t oscGateSamples = 0;


// -- ENVELOPE STATE --
bool midiNoteHeld = false;  // True while a MIDI note is physically held
bool envGateHeld = false;   // Current gate state fed to env.Process()

// -- PULSAR ENV --
enum PulsarMode { PULSAR_MODE_SEQ,
                  PULSAR_MODE_MIDI,
                  PULSAR_MODE_OSC };
PulsarMode currentPulsarMode = PULSAR_MODE_SEQ;
float pulsarReleaseTime = 0.02f;
bool lastPulsarEnvActive = false;
float pulsarPeriodModCoeff = 0.0f;
bool manualPulsarTrigger = false;
bool pulsarMidiTrigger = false;


// -- SAMPLE&HOLD / RANDOM VOLTAGE --
enum RandomMode { RANDOM_MODE_SEQ,
                  RANDOM_MODE_PULSAR,
                  RANDOM_MODE_MIDI };
RandomMode currentRandomMode = RANDOM_MODE_SEQ;
float currentRandomValue = 0.0f;
bool randomMidiTrigger = false;

// -- REVERB --
float reverbMix;  // REVERB MIX COEFF

// -- MIDI --
#define MIDI_RX_PIN 14  // USART1 Rx (Digital pin 30)
  // MIDI OBJECT
MIDI_CREATE_INSTANCE(HardwareSerial, Serial1, MIDI);
// --
bool quantizeToMidi = false;       // Enable/disable MIDI quantization mode
float baseFreqComplex = 261.63f;   // Base frequency for complex osc (C4 = 261.63Hz)
float baseFreqMod = 261.63f;       // Base frequency for mod osc (C4 = 261.63Hz)
float lastMidiNoteFreq = 261.63f;  // Last received MIDI note frequency
bool midiNoteReceived = false;     // Track if we've received a MIDI note in quantize mode

// -- MIDI CLOCK SYNC --
bool midiClockSync = false;               // Enable/disable MIDI clock sync
bool midiClockActive = false;             // Whether MIDI clock is currently being received
uint32_t midiClockTicks = 0;              // Counter for MIDI clock ticks
uint32_t midiClockSamplesPerTick = 0;     // Samples between MIDI clock ticks (calculated from tempo)
float midiTempo = 120.0f;                 // Current MIDI tempo in BPM
uint32_t lastMidiClockTime = 0;           // Last time we received a MIDI clock message
const uint32_t MIDI_CLOCK_TIMEOUT = 500;  // Timeout in milliseconds (0.5 seconds)


// -- CLOCK DIVISIONS (for MIDI sync mode) --
const float clockDivisions[] = { 1.0f, 2.0f, 4.0f, 8.0f, 12.0f, 16.0f, 24.0f, 32.0f };
const int NUM_DIVISIONS = 8;
int currentDivisionIndex = 0;  // 0 = 1/1, 1 = 1/2, etc.
float currentDivision = 1.0f;  // Current clock division multiplier


// -- SEQUENCER --
int seqCurrentStep = 0;
bool seqStepEnabled[5] = { true, true, true, true, true };  // All steps ON by default
float seqStepCV[5] = { 0.0f };                              // Stores current CV from MUX1 0-4
float seqClockSpeed = 100.0f;
int seqMaxSteps = 5;  // Default sequence length
// AUDIO INTERRUPT TIMING
uint32_t seqSampleCounter = 0;  // Counts samples to trigger the next step
float activeSeqCV = 0.0f;       // The CV of the currently active step
// SAMPLE RATE
uint32_t samplesPerTick = 48000;  // default, will be updated in updateParameters()

// SEQUENCER MODES
enum SeqTriggerMode { SEQ_TRIGGER_CLOCK,
                      SEQ_TRIGGER_PULSAR,
                      SEQ_TRIGGER_MIDI };
SeqTriggerMode currentSeqTriggerMode = SEQ_TRIGGER_CLOCK;  // Default Mode
bool midiTriggerPending = false;                           // Flag to catch MIDI notes for the sequencer
int currentMidiNote = 60;                                  // Default to Middle C when no midi is detected
uint8_t midiTriggerCounter = 0;
const uint8_t MIDI_TRIGGER_HOLDOFF = 10;  // Adjust as needed (5-20 is good)

// -- OPTIMIZATION VARIABLES --
float rawModulationValues[7] = { 0 };  // Pre-calculated modulation values
float ln2 = 0.69314718056f;            // ln(2) for fast exp approximations
uint32_t modUpdateCounter = 0;         // REMOVE THE DUPLICATE IN AudioCallback
const uint32_t MOD_UPDATE_RATE = 16;   //

// -- FAST MATH APPROXIMATIONS --
inline float fast_exp2_approx(float x) {
  // Fast 2^x approximation using Taylor series expansion
  x = 1.0f + x * ln2;  // First-order approximation
  // Second-order improvement for better accuracy
  return x * (1.0f + (x - 1.0f) * 0.5f);
}

inline float fast_pow_approx(float base, float exponent) {
  // Simple pow approximation for audio use
  // Works well for exponent in range 0-1
  return 1.0f + (base - 1.0f) * exponent;
}

inline float fast_lpg_freq(float ctrl) {
  // Clamp ctrl to [0,1]
  if (ctrl < 0.0f) ctrl = 0.0f;
  if (ctrl > 1.0f) ctrl = 1.0f;

  // Linear interpolation between table values
  float idx = ctrl * (LPG_TABLE_SIZE - 1);
  int i = (int)idx;
  if (i >= LPG_TABLE_SIZE - 1) return lpgFreqTable[LPG_TABLE_SIZE - 1];
  float frac = idx - i;
  return lpgFreqTable[i] + frac * (lpgFreqTable[i + 1] - lpgFreqTable[i]);
}

// Soft clipper for SVF input protection
inline float svf_input_protect(float x) {
  // Prevent extreme values that cause SVF instability
  if (x > 1.5f) return 1.5f;
  if (x < -1.5f) return -1.5f;
  // Soft clip near the edges to prevent harsh edges
  if (x > 1.0f) return 1.0f + (x - 1.0f) * 0.25f;
  if (x < -1.0f) return -1.0f + (x + 1.0f) * 0.25f;
  return x;
}

// NaN and bad float detection
inline bool isBadFloat(float x) {
  // Check for NaN (x != x) and infinity
  return (x != x) || (x > 1e10f) || (x < -1e10f);
}

// Get frequency ratio from MIDI note relative to C4 (note 60)
inline float getMidiTransposeRatio(int midiNote) {
  // C4 = note 60, ratio = 2^((note - 60)/12)
  float semitones = (float)(midiNote - 60);
  return powf(2.0f, semitones / 12.0f);
}
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
void loop() {

  // MIDI PROCESSING
  while (MIDI.read()) {
    // MIDI callbacks handle the events
  }

  checkMidiClockActivity();  // ADD THIS LINE


  // READ BUTTON MATRICES
  if (millis() - lastMatrixRead > MATRIX_READ_INTERVAL) {
    readButtonMatrix();
    readButtonMatrix2();
    printButtonChanges();  //BUTTON FNCs
    lastMatrixRead = millis();
  }

  // READ POTENTIOMETERS AND UPDATE PARAMETERS
  if (millis() - lastPotRead > POT_READ_INTERVAL) {
    readPotentiometers();
    updateParameters();  // UPDATE PARAMS
    lastPotRead = millis();
  }

  // CPU & DEBUG PRINTING (Runs every 0.5 seconds)
  /*
  if (millis() - lastCpuPrint >= 500) {
    lastCpuPrint = millis();

    // CPU LOAD REPORTING
    float avgLoad = cpuMeter.GetAvgCpuLoad();
    float maxLoad = cpuMeter.GetMaxCpuLoad();

    Serial.print("CPU Load: ");
    Serial.print(avgLoad * 100.0f);
    Serial.print("% | Max: ");
    Serial.print(maxLoad * 100.0f);
    Serial.println("%");
  }*/
}

// -- UPDATE PARAMETERS --
void updateParameters() {
  // -- OSCILLATORS --

  // FINE TUNE
  // 3 cents is 3/1200 of an octave.
  float fineRange = 3.0f / 12.0f;

  // -- COMPLEX OSCILLATOR --
  // PITCH
  complexOscFreq = fmap(potValues[16] / 65535.0f, 25.0f, 1760.0f, Mapping::EXP);

  // Pot 15: Complex Osc Frequency Modulation Amount
  complexOscFreqModDepth = potValues[15] / 65535.0f;

  // Pot 17: Fine Tune Complex Oscillator (+/- 3 cents)
  complexOscFine = ((potValues[17] / 65535.0f) * 2.0f - 1.0f) * fineRange;

  // TIMBRE/MORPH CONTROL
  complexOscMorphMix = potValues[20] / 65535.0f;

  // WAVEFOLDER (0.0 to 1.0f)
  float complexOscWFPot = potValues[19] / 65535.0f;
  complexOscWF = 1.0f + (19.0f * complexOscWFPot);

  // Pot 18: Wavefolder Modulation Amount
  complexOscWFModDepth = potValues[18] / 65535.0f;

  // LPG
  // Pot 21: Amount of modulation for Folded Signal LPG
  foldedLpgModAmount = fmap(potValues[21] / 65535.0f, 0.0f, 0.98f, Mapping::LINEAR);

  // Pot 22: Channel 1 Sig Level
  complexOscSigLevel = fmap(potValues[22] / 65535.0f, 0.0f, 0.98f, Mapping::EXP);

  // -- MODULATION OSCILLATOR --
  // PITCH
  modulationOscFreq = fmap(potValues[11] / 65535.0f, 0.1f, 1000.0f, Mapping::EXP);

  // Pot 10: Amount of modulation applied to Mod Osc Frequency
  modulationFreqModDepth = potValues[10] / 65535.0f;

  // Pot 12: Fine Tune Modulation Oscillator (+/- 3 cents)
  modulationFine = ((potValues[12] / 65535.0f) * 2.0f - 1.0f) * fineRange;

  // MODULATION (FM/AM)
  // Pot 14: Modulation Depth (FM or AM depth)
  modulationOscMod = potValues[14] / 65535.0f;

  // Pot 13: Amount of modulation applied to Mod Osc Modulation Depth (FM/AM amount)
  modulationOscModCoeffDepth = potValues[13] / 65535.0f;

  // LPG
  // Pot 23: Amount of modulation for Mod Osc Signal LPG
  modOscLpgModAmount = fmap(potValues[23] / 65535.0f, 0.0f, 0.98f, Mapping::LINEAR);

  // Pot 24: Channel 2 Sig Level
  modOscSigLevel = fmap(potValues[24] / 65535.0f, 0.0f, 0.98f, Mapping::EXP);

  // -- ENVELOPE [Buchla ASD config] --
  float minTime = 0.002f;
  float maxTime = 5.0f;

  // Attack Time (Logarithmic)
  attackTime = fmap(potValues[5] / 65535.0f, minTime, maxTime, Mapping::EXP);
  env.SetAttackTime(attackTime);

  // Sustain Duration (Logarithmic)
  sustainDuration = fmap(potValues[6] / 65535.0f, 0.02f, maxTime, Mapping::EXP);

  // TRANSIENT mode: gate pulse length = sustain pot value (minimum 20ms)
  transientGateSamples = (uint32_t)(sustainDuration * sampleRate);
  uint32_t minTransientSamples = (uint32_t)(0.02f * sampleRate);  // 20ms minimum
  if (transientGateSamples < minTransientSamples) transientGateSamples = minTransientSamples;

  // SUSTAIN mode: gate length = sustain pot value + 300ms minimum
  uint32_t minSustainGate = (uint32_t)(0.1f * sampleRate);  // 300ms minimum
  sustainGateSamples = (uint32_t)(sustainDuration * sampleRate);
  if (sustainGateSamples < minSustainGate) sustainGateSamples = minSustainGate;

    // Release Time (Logarithmic)
  // When in oscillate mode, reduce the range to 50%
  float releasePotNorm = potValues[7] / 65535.0f;
  
  if (currentEnvMode == ENV_MODE_OSCILLATE) {
    // OSCILLATE MODE: 50% of normal range
    // Map pot (0-1) to range (minTime to maxTime/2)
    float oscillateMaxTime = maxTime * 0.2f;
    releaseTime = fmap(releasePotNorm, minTime, oscillateMaxTime, Mapping::EXP);
  } else {
    // Normal mode: full range
    releaseTime = fmap(releasePotNorm, minTime, maxTime, Mapping::EXP);
  }
  
  env.SetReleaseTime(releaseTime);
  env.SetDecayTime(0.0f);
  env.SetSustainLevel(1.0f);

  // -- PULSAR --
  // Pot 9: Base Pulsar Release Time
  float pulsarReleasePot = potValues[9] / 65535.0f;

  // Logarithmic mapping: 20ms to 5000ms (0.02s to 5.0s)
  float pulsarMinTime = 0.02f;  // 20ms - very short decay
  float pulsarMaxTime = 5.0f;   // 5000ms - long decay
  float pulsarTimeRatio = pulsarMaxTime / pulsarMinTime;

  // Base release time from pot (logarithmic)
  float basePulsarRelease = pulsarMinTime * powf(pulsarTimeRatio, pulsarReleasePot);

  // Subtract modulation (clamped) to ensure time decreases
  float adjustedPulsarTime = basePulsarRelease - (2.0f * pulsarPeriodModCoeff);  // Scale modulation appropriately
  if (adjustedPulsarTime < pulsarMinTime) adjustedPulsarTime = pulsarMinTime;
  if (adjustedPulsarTime > pulsarMaxTime) adjustedPulsarTime = pulsarMaxTime;

  pulsarReleaseTime = adjustedPulsarTime;
  pulsar.SetReleaseTime(pulsarReleaseTime);

  // -- SEQUENCER --
  // Update Sequencer CV steps from MUX1 Channels 0-4
  for (int i = 0; i < 5; i++) {
    // Store normalized 0.0 to 1.0 values
    seqStepCV[i] = fmap(potValues[i] / 65535.0f, 0.0f, 1.0f, Mapping::EXP);
  }
  // -- CLOCK --
  if (midiClockSync) {
    // When in MIDI sync mode, the pot controls clock division
    updateClockDivision();
    // Don't update seqClockSpeed or samplesPerTick in this mode
    // The sequencer timing is handled by MIDI clock
  } else {
    // Free-running clock mode - original behavior
    float clockPot = potValues[25] / 65535.0f;
    seqClockSpeed = 0.1f * powf(40000.0f, (1.0f - clockPot));

    // CLOCK CLAMPING
    if (seqClockSpeed < 0.1f) seqClockSpeed = 0.1f;
    if (seqClockSpeed > 4000.0f) seqClockSpeed = 4000.0f;

    samplesPerTick = (uint32_t)((seqClockSpeed / 1000.0f) * DAISY.get_samplerate());
    if (samplesPerTick < 1) samplesPerTick = 1;
  }


  // -- REVERB --
  reverbMix = potValues[26] / 65535.0f;  // REVERB MIX CONTROL
}

// -- MIDI NOTE HANDLING
void handleNoteOn(byte channel, byte note, byte velocity) {
  if (velocity > 0) {
    currentMidiNote = note;
    midiTriggerPending = true;
    midiTriggerCounter = MIDI_TRIGGER_HOLDOFF;
    lastMidiNoteFreq = getMidiTransposeRatio(note);
    midiNoteReceived = true;
    midiNoteHeld = true;
    pulsarMidiTrigger = true;
    randomMidiTrigger = true;
    envMidiTrigger = true;
    //envTrigger = true;
  }
}

void handleNoteOff(byte channel, byte note, byte velocity) {
  midiNoteHeld = false;
}

// -- MIDI CLOCK HANDLING --
void handleMidiClock() {
  // Called on each MIDI clock tick (24 ticks per quarter note)
  uint32_t now = millis();

  // Mark that MIDI clock is active
  midiClockActive = true;

  // Calculate tempo from tick interval (only when sync is enabled)
  if (midiClockSync) {
    if (lastMidiClockTime > 0) {
      uint32_t tickInterval = now - lastMidiClockTime;
      // 24 ticks per quarter note, so quarter note interval = tickInterval * 24
      float quarterNoteInterval = tickInterval * 24.0f;
      if (quarterNoteInterval > 0) {
        midiTempo = 60000.0f / quarterNoteInterval;
        // Clamp tempo to reasonable range
        if (midiTempo < 40.0f) midiTempo = 40.0f;
        if (midiTempo > 240.0f) midiTempo = 240.0f;

        // Calculate samples per MIDI clock tick based on current division
        // One tick = 1/24 of a quarter note, then multiply by division
        float secondsPerTick = 60.0f / (midiTempo * 24.0f);
        // Apply division: larger division = longer interval between steps
        midiClockSamplesPerTick = (uint32_t)(secondsPerTick * sampleRate * currentDivision);
        if (midiClockSamplesPerTick < 1) midiClockSamplesPerTick = 1;
      }
    }
  }
  lastMidiClockTime = now;
  midiClockTicks++;
}

// -- CHECK MIDI CLOCK ACTIVITY --
void checkMidiClockActivity() {
  // If MIDI clock sync is enabled, check if we've received a clock message recently
  if (midiClockSync) {
    uint32_t now = millis();
    if (now - lastMidiClockTime > MIDI_CLOCK_TIMEOUT) {
      midiClockActive = false;
      midiClockSamplesPerTick = 0;  // Invalidate the samples per tick
    }
  }
}
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

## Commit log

2025-09-08 KiCad Project Created
    [WEASEL_KiCad.kicad_pcb, WEASEL_KiCad.kicad_sch]
2025-09-09 Layout design
    [WEASEL_KiCad.kicad_pcb]
2025-09-12 Virtual Patch bay added to schematic
    Virtual modular patch bay added
    [WEASEL_KiCad.kicad_pcb, WEASEL_KiCad.kicad_sch]
2025-09-22 FM Adjustments
    - Fixed pitch drift
2025-09-23 AM Addition
    - Introduces AM
    - Pitch shift needs fixing
2025-09-23 Analogue filtering
    Added same filter to modOsc
2025-09-25 Schematic and PCB Changes
    [WEASEL_KiCad.kicad_pcb, WEASEL_KiCad.kicad_sch]
2025-09-26 Schematic update
    - fixed unconnected terminals
2025-09-26 pcb update
    update based on schematic changes
    [WEASEL_KiCad.kicad_pcb, WEASEL_KiCad.kicad_sch]
2025-09-26 Update Schematic
    - changed MUX to module instead of SMD IC
    [WEASEL_KiCad.kicad_pcb, WEASEL_KiCad.kicad_sch]
2025-09-26 Schematic and PCB Update
    - PCB changes
    -
    [WEASEL_KiCad.kicad_pcb, WEASEL_KiCad.kicad_sch]
2025-09-27 LPG Modifications
    Added LPG mod level control
    - LP - both pots only control cut-off - static signal level
2025-10-07 PCB Layout v1.0
    - Finished PCB Layout v1.0
    - Gerbers generated
    [WEASEL_KiCad.kicad_pcb, WEASEL_KiCad.kicad_sch]
2025-10-07 PCB Gerbers
    [WEASEL_KiCad-B_Cu.gbr, WEASEL_KiCad-B_Mask.gbr, WEASEL_KiCad-B_Paste.gbr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]
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2025-10-08 PCB & Schematic updates
    Created prototype virtual modular matrix
    [WEASEL_KiCad.kicad_pcb, WEASEL_KiCad.kicad_sch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]
2025-10-09 PCB & Schematic update
    - Removed unnecessary capacitors for each pot. Each MUX signal pin has a capacitor to filter the signal.
    - New board layout
    - More compact and organised.
    [WEASEL_KiCad-B_Cu.gbr, WEASEL_KiCad-B_Mask.gbr, WEASEL_KiCad-B_Paste.gbr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]
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2025-10-13 prototype mod matrix added
    - Modified code to add new mod matrix (virtual button matrix)
2025-10-13 Sequencer CV Modulation
    - Added Sequencer CV to modOsc Pitch modulation via button matrix
    - removed default setting where its pitch follows the sequencer CV
    - added the sequencer cv back to the pitch when B0 and A1 are both high
2025-10-13 sequencer cv modulates complexOsc Pitch
    - removed default setting where complexOsc follows sequencerCv.
    - re-implemented the pitch control for when B0 and A3 are both high for the complexOsc
2025-10-14 button Matrix Prototype pcb
    [WEASEL_KiCad_buttonMatrix.kicad_pcb, WEASEL_KiCad_buttonMatrix.kicad_sch]
2025-10-14 PulsarOsc Modulation
    - added modulation to the modOsc pitch from pulsarOsc
    - when B2 and A1 are high, this modulation occurs
2025-10-16 Prototype Button Matrix PCB
    [WEASEL_KiCad_buttonMatrix-B_Cu.gbr, WEASEL_KiCad_buttonMatrix-B_Mask.gbr, WEASEL_KiCad_buttonMatrix-B_Paste.gbr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]
2025-10-16 Button Matrix Prototype Update
    [WEASEL_KiCad_buttonMatrix-B_Cu.gbr, WEASEL_KiCad_buttonMatrix-B_Mask.gbr, WEASEL_KiCad_buttonMatrix-B_Paste.gbr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]
2025-10-16 PCB Button Matrix Update
    [WEASEL_KiCad_buttonMatrix-B_Cu.gbr, WEASEL_KiCad_buttonMatrix-B_Mask.gbr, WEASEL_KiCad_buttonMatrix-B_Paste.gbr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]
2025-10-21 Front panel PCB
    [WEASEL_KiCad.kicad_pcb]
2025-10-22 Front panel update
    [WEASEL_KiCad.kicad_pcb]
2025-10-24 front panel v0.1
    [WEASEL_KiCad_frontPanel-B_Cu.gbr, WEASEL_KiCad_frontPanel-B_Mask.gbr, WEASEL_KiCad_frontPanel-B_Paste.gbr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]
2025-10-24 Front_panel v0.1
    [WEASEL_KiCad_frontPanel-B_Cu.gbr, WEASEL_KiCad_frontPanel-B_Mask.gbr, WEASEL_KiCad_frontPanel-B_Paste.gbr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]
2025-10-25 pulserEnv - switched to ADSR
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2025-10-27 Main PCB fix
2025-10-27 PCB & Gerber updates
    [WEASEL_KiCad-B_Cu.gbr, WEASEL_KiCad-B_Mask.gbr, WEASEL_KiCad-B_Paste.gbr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]
2025-10-28 FW update - prototype board
    [WEASEL_KiCad.kicad_sch]
2025-10-28 PCB V2.0
    [WEASEL_KiCad.kicad_sch]
2025-10-29 PCB & UI 2.0
    [WEASEL_KiCad.kicad_sch]
2025-10-30 PCB & UI 2.0
    Front Panel final
    Back panel Final
    [WEASEL_KiCad-B_Cu.gbr, WEASEL_KiCad-B_Mask.gbr, WEASEL_KiCad-B_Paste.gbr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]
2026-02-03 EASEL Plugin Waveforms
    - extracted SINE, SAW, SQU and TRI waves from Arturia's EASEL V plugin
    - NOTE: Did not capture the simulated circuit artifacts - only captured 1 cycle for LUTs
2026-02-06 PCB UPDATE
    Small update to PCB
    - Minor change to FW on clock speed
    [WEASEL_KiCad-B_Cu.gbr, WEASEL_KiCad-B_Mask.gbr, WEASEL_KiCad-B_Paste.gbr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]
2026-02-08 PCB and Firmware Updates
    - Updated PCBs
    - Updated firmware to add sequencer trigger toggle - sequencer can now be triggered by pulser. Midi is WIP
    - Updated Pot names in Serial
    - Fixed X1 Row button issues
    [WEASEL_KiCad-B_Cu.gbr, WEASEL_KiCad-B_Mask.gbr, WEASEL_KiCad-B_Paste.gbr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]
2026-02-08 Smoothed POTS
    [WEASEL_KiCad.kicad_sch]
2026-02-09 MIDI IN pots change
    Swapped Y4 and RX pins
    [WEASEL_KiCad.kicad_sch]
2026-02-09 Update MIDI Toggle for Oscillators
    - Oscillators no longer receive MIDI note information from external hardware. Instead this is now a quantise button to quantise the frequencies of the oscillators
    [WEASEL_FW.ino]
2026-02-09 Y4 Pin and MIDI In pin swap
    - Swapped physical wiring of pins D14 and D30
    - Updated PCB
    [WEASEL_KiCad-B_Cu.gbr, WEASEL_KiCad-B_Mask.gbr, WEASEL_KiCad-B_Paste.gbr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]
2026-02-10 PCB Update
    Standoffs
    [WEASEL_KiCad-B_Cu.gbr, WEASEL_KiCad-B_Mask.gbr, WEASEL_KiCad-B_Paste.gbr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]
2026-02-11 Optimisation
    - Less intensive calculations out of AudioCallback()
    - Fixed Clock pot
    - Fixed Pulser Pot
    - Fixed Buttons
    [WEASEL_FW.ino]
2026-02-11 PCB Update
    Added 5V Power Input
    [WEASEL_KiCad.kicad_sch]
2026-02-12 PCB Update
    - Fixed Panel holes that were removed
    - Added DC 5V power socket to VIN
    - Added M2 stand-off holes
    [WEASEL_KiCad-B_Cu.gbr, WEASEL_KiCad-B_Mask.gbr, WEASEL_KiCad-B_Paste.gbr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]
2026-05-14 PCB & Schematic Changes
    Added Shift registers for buttons
    Added I2C LED Drivers for better visual feedback
    - Removed Button matrices
    [WEASEL_KiCad-B_Cu.gbr, WEASEL_KiCad-B_Mask.gbr, WEASEL_KiCad-B_Paste.gbr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]
2026-05-14 PCB Footprint Updates
    - changed 6N138 to DIP-8 package
    [WEASEL_KiCad.kicad_pcb, WEASEL_KiCad.kicad_sch, WEASEL_KiCad_MainBoard.kicad_pcb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]
2026-05-14 pcb updates
    [WEASEL_KiCad_PANELS.kicad_pcb, WEASEL_PANELS_bom.csv, WEASEL_PANELS_designators.csv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]
2026-05-14 PCB Revisions
    [WEASEL_KiCad.kicad_pcb, WEASEL_KiCad_MainBoard.kicad_pcb, WEASEL_KiCad_PANELS.kicad_pcb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]
